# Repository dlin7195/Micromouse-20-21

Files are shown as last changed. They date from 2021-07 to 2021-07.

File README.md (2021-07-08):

# Micromouse-20-21
Maze-solving vehicle implemented using an STM32F405RGT6 microcontroller.
The vehicle detects maze walls using readings from infrared emitter and receiver pairs.
Designed breakout board for IR receivers and emitters using EAGLE.
Uses encoder readings fed into a PID controller for distance and rotation control.

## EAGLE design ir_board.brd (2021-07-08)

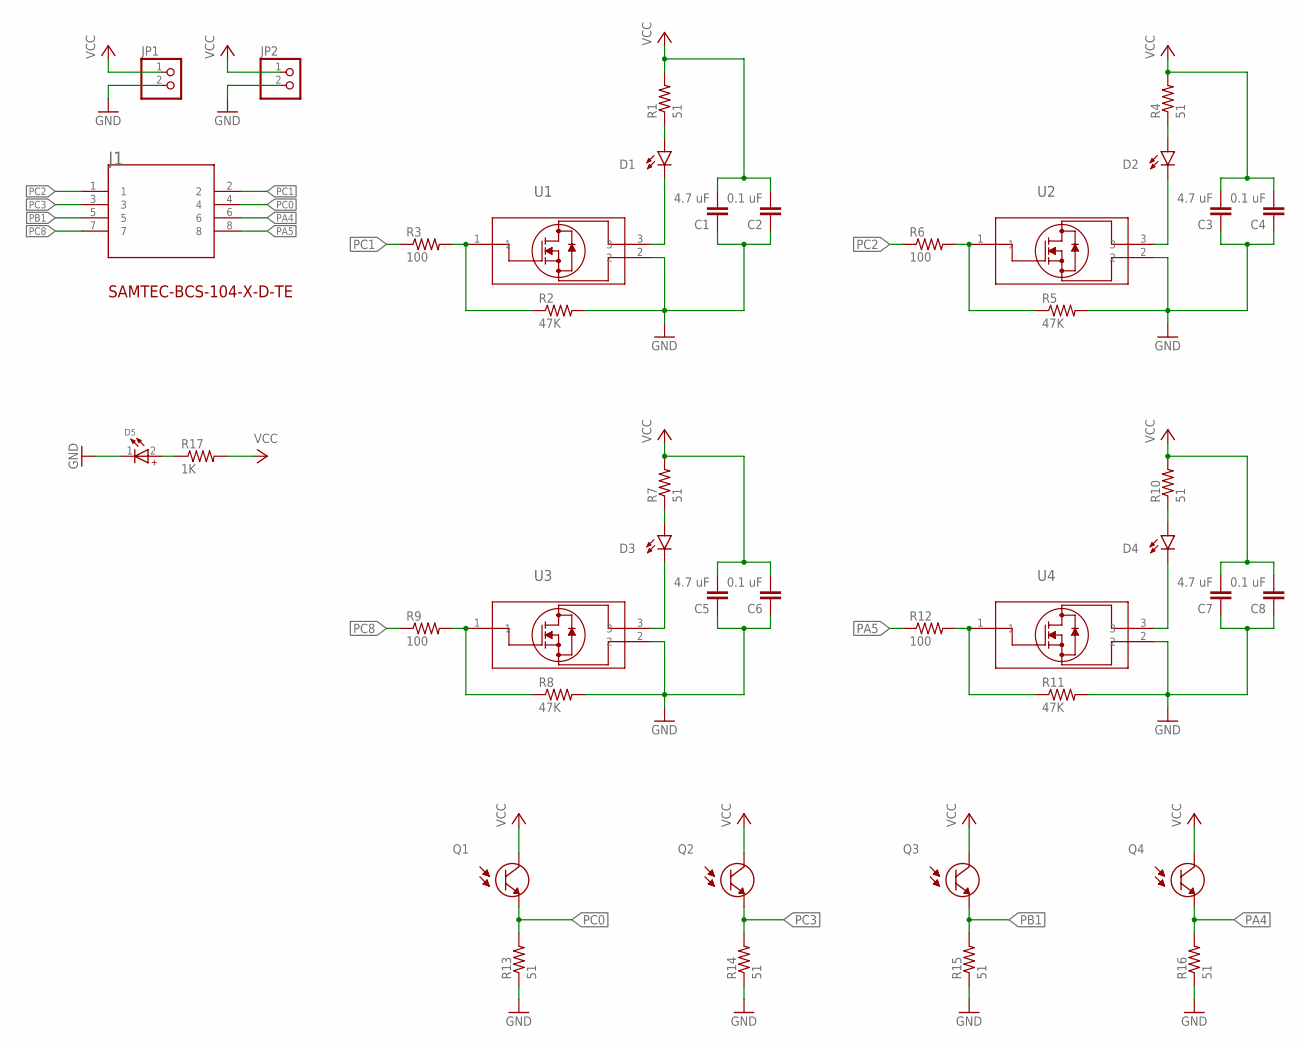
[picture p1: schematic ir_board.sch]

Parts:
C1, C3, C5, C7: 4.7 uF; C0805
C2, C4, C6, C8: 0.1 uF; C0805
D1, D2, D3, D4: LED5MM
D5: WL-SMCW_0805_150080BS75000; WL-SMCW_0805
J1: SAMTEC-BCS-104-X-D-TEJ; SAMTEC-BCS-104-X-D-TE
JP1, JP2: PINHD-1X2; 1X02
Q1, Q2, Q3, Q4: SFH_313_FA-3/4; XDCR_SFH_313_FA-3/4
R1, R4, R7, R10, R13, R14, R15, R16: 51; R0805
R2, R5, R8, R11: 47K; R0805
R3, R6, R9, R12: 100; R0805
R17: 1K; R0805
U1, U2, U3, U4: 2N7002LT1G; SOT-23_3L_ONS

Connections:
GND: C1.1, C2.1, C3.1, C4.1, C5.1, C6.1, C7.1, C8.1, D5.1 (-), JP1.2, JP2.2, R2.2, R5.2, R8.2, R11.2, R13.1, R14.1, R15.1, R16.1, U1.2, U2.2, U3.2, U4.2
unnamed: R2.1, R3.2, U1.1
unnamed: D1.K (C), U1.3
unnamed: D5.2 (+), R17.1
unnamed: D2.A, R4.1
unnamed: D2.K (C), U2.3
unnamed: R8.1, R9.2, U3.1
unnamed: D3.A, R7.1
unnamed: R5.1, R6.2, U2.1
unnamed: R11.1, R12.2, U4.1
unnamed: D4.K (C), U4.3
unnamed: D3.K (C), U3.3
unnamed: D4.A, R10.1
unnamed: D1.A, R1.1
PA4: J1.6, Q4.1 (E), R16.2
PA5: J1.8, R12.1
PB1: J1.5, Q3.1 (E), R15.2
PC0: J1.4, Q1.1 (E), R13.2
PC1: J1.2, R3.1
PC2: J1.1, R6.1
PC3: J1.3, Q2.1 (E), R14.2
PC8: J1.7, R9.1
VCC: C1.2, C2.2, C3.2, C4.2, C5.2, C6.2, C7.2, C8.2, JP1.1, JP2.1, Q1.2 (C), Q2.2 (C), Q3.2 (C), Q4.2 (C), R1.2, R4.2, R7.2, R10.2, R17.2

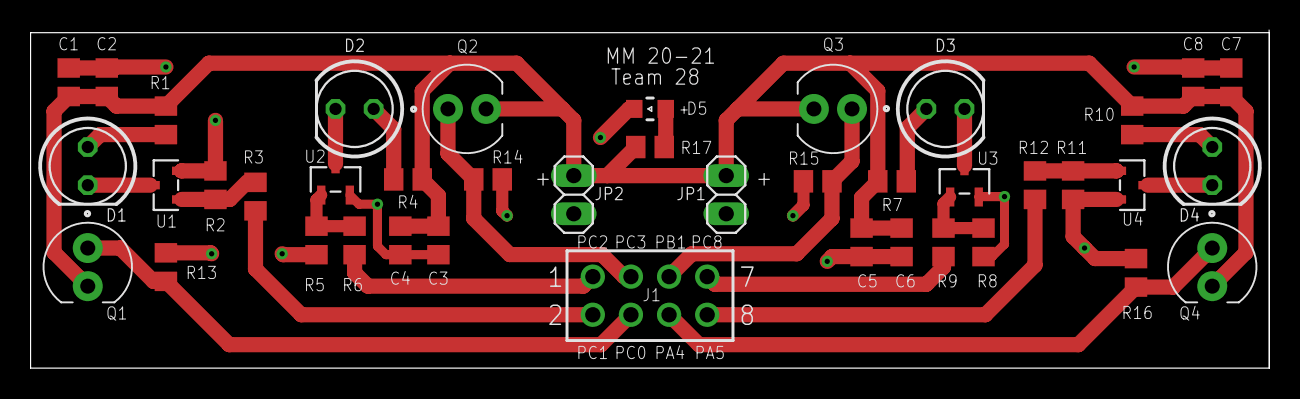
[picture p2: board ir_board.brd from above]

Board: 2 copper layers, 82.5 x 22.4 mm, 41 parts (0 on the bottom side), 23 nets.

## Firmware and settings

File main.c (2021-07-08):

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
/* Includes ------------------------------------------------------------------*/
#include "main.h"

/* USER CODE BEGIN Includes */
#include "encoders.h"
#include "motors.h"
#include "controller.h"
#include "delay.h"
#include "irs.h"
#include "math.h"
/* USER CODE END Includes */

ADC_HandleTypeDef hadc1;
DMA_HandleTypeDef hdma_adc1;

TIM_HandleTypeDef htim2;
TIM_HandleTypeDef htim4;
TIM_HandleTypeDef htim8;

/* USER CODE BEGIN PV */

int16_t left_counts = 0;
int16_t right_counts = 0;

uint16_t curLeft = 0;
uint16_t curFront = 0;
uint16_t curRight = 0;

uint16_t prevFront = 0;
uint16_t prevLeft = 0;
uint16_t prevRight = 0;

uint16_t leftDelta = 200;
uint16_t frontDelta = 50;
uint16_t rightDelta = 200;


/* USER CODE END PV */

void SystemClock_Config(void);
static void MX_GPIO_Init(void);
static void MX_DMA_Init(void);
static void MX_TIM2_Init(void);
static void MX_TIM8_Init(void);
static void MX_TIM4_Init(void);
static void MX_ADC1_Init(void);
/**
  * @brief  The application entry point.
  * @retval int
  */
int main(void)
{
  /* MCU Configuration--------------------------------------------------------*/

  /* Reset of all peripherals, Initializes the Flash interface and the Systick. */

 	HAL_Init();


  /* USER CODE BEGIN Init */

  Delay_Init();

  /* USER CODE END Init */

  /* Configure the system clock */
  SystemClock_Config();

  /* Initialize all configured peripherals */
  MX_GPIO_Init();
  MX_DMA_Init();
  MX_TIM2_Init();
  MX_TIM8_Init();
  MX_TIM4_Init();
  MX_ADC1_Init();
  /* USER CODE BEGIN 2 */

  HAL_TIM_Encoder_Start(&htim2, TIM_CHANNEL_ALL);
  HAL_TIM_Encoder_Start(&htim8, TIM_CHANNEL_ALL);

  HAL_TIM_PWM_Start(&htim4, TIM_CHANNEL_1);
  HAL_TIM_PWM_Start(&htim4, TIM_CHANNEL_2);
  HAL_TIM_PWM_Start(&htim4, TIM_CHANNEL_3);
  HAL_TIM_PWM_Start(&htim4, TIM_CHANNEL_4);

    // set each motor to different speed and direction
  float left = 0.0;
  float right = 0.0;
  setMotorRPWM(right);  // spin forwards
  setMotorLPWM(left);  // spin backwards

 /*
  move(1);
  turn(-1);
  move(1);
  turn(1);
  move(2);
  turn(1);
  move(1); */

  /* USER CODE END 2 */

  /* Infinite loop */
  /* USER CODE BEGIN WHILE */
  while (1)
  {
	left_counts = (int16_t) TIM2->CNT;
	right_counts = (int16_t) TIM8->CNT;

	curLeft = readLeftIR();
	curFront = readFrontIR();
	curRight = readRightIR();

	if (prevFront != 0)
	{
		if ((curFront - prevFront) > frontDelta)
		{
			//if (fabs(curLeft - prevLeft) > leftDelta)
			if (curRight < 1000)
			{
				turn(-1);  //turn right
			}
			//else if (fabs(curRight - prevRight) > rightDelta)
			else if (curLeft < 950)
			{
				turn(1);  // turn right
			}
			else
			{
				// walls on 3 sides
				break;
			}
		}
		else
		{
			move(1);
		}
		//prevFront = curFront;
	}
	//else
	//{
		//prevFront = curFront;
		/*if (curFront < 700)
		{
			move(1);
		}
		else
		{
		if (readLeftIR() < 1580)
		{
			turn(1);
		}
			if (readRightIR() < 1400)
			{
				turn(-1);
			}
			else if (readLeftIR() < 750)
			{
				turn(1);
			}
		}*/
	//}
    prevFront = curFront;
    prevLeft = curLeft;
    prevRight = curRight;

	/*if (readFrontIR() > 800)
	{
		if (readLeftIR() > 1500)
		{
			if (readRightIR() < 770)
			{
				turn(-1);
				//move(1);
			}
		}
		else
		{
			if (readRightIR() > 700)
			{
				if (readLeftIR() < 2000)
				{
					turn(1);
					//move(1);
				}
			}
		}
	}
	else
	{
		move(1);
	} */

    /* USER CODE END WHILE */

    /* USER CODE BEGIN 3 */
  }
  /* USER CODE END 3 */
}

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
/* USER CODE BEGIN 4 */

void HAL_GPIO_EXTI_Callback(uint16_t GPIO_Pin)
{
  if(GPIO_Pin == PushButton_Pin)
  {
	   /* Your code goes here */
	  if(HAL_GPIO_ReadPin(PushButton_GPIO_Port, PushButton_Pin) == GPIO_PIN_SET)
	  {
		  HAL_GPIO_WritePin(LED_GPIO_Port, LED_Pin, GPIO_PIN_RESET);
	  }
	  else
	  {
		  HAL_GPIO_WritePin(LED_GPIO_Port, LED_Pin, GPIO_PIN_SET);
	  }
  }
}

ADC_HandleTypeDef* Get_HADC1_Ptr(void)
{
	return &hadc1;
}


/* USER CODE END 4 */
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


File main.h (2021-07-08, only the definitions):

#define LED_Pin GPIO_PIN_2
#define LED_GPIO_Port GPIOA
#define PushButton_Pin GPIO_PIN_3
#define PushButton_GPIO_Port GPIOA
#define PushButton_EXTI_IRQn EXTI3_IRQn
#define RightEmitter_Pin GPIO_PIN_4
#define RightEmitter_GPIO_Port GPIOA
#define RightReceiver_Pin GPIO_PIN_5
#define RightReceiver_GPIO_Port GPIOA
#define FrontEmitter_Pin GPIO_PIN_6
#define FrontEmitter_GPIO_Port GPIOA
#define FrontReceiver_Pin GPIO_PIN_7
#define FrontReceiver_GPIO_Port GPIOA
#define LeftEmitter_Pin GPIO_PIN_4
#define LeftEmitter_GPIO_Port GPIOC
#define LeftReceiver_Pin GPIO_PIN_5
#define LeftReceiver_GPIO_Port GPIOC

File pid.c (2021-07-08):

/*
 * pid.c
 *
 *  Template created on: Sep 27, 2020
 *      Author: Tyler Price
 */

#include "main.h"
#include "motors.h"
#include "encoders.h"
#include "math.h"

// define variables
int angleError = 0;
int oldAngleError = 0;
float distanceError = 0;
float oldDistanceError = 0;
float angleCorrection = 0;
float distanceCorrection = 0;
float kPw = 0.004;
float kDw = 0.02;
float kPx = 0.0042;
float kDx = 0.02;

int targetAngle = 0;
int targetDistance = 0;
int isAngleDone = 0;
int isDistanceDone = 0;
int isDone = 0;
int i = 0;

int encoderCount_avg = 0;

void resetPID()
{
	/*
	 * Rreset all the PID-assisting variables defined in this file to default values.
	 * Reset your motors and encoder counts.
	 *
	 * Reset distance and error goal values (+ oldDistanceError and oldAngleError) to zero.
	 */
	angleError = 0;
	distanceError = 0;
	angleCorrection = 0;
	distanceCorrection = 0;

	resetMotors();
	resetEncoders();

	oldDistanceError = 0;
	oldAngleError = 0;

	targetAngle = 0;
	targetDistance = 0;
	isAngleDone = 0;
	isDistanceDone = 0;
	isDone = 0;
	i = 0;

	encoderCount_avg = 0;
	return;
}

void updatePID()
{
	/*
	 * PID logic. It should do the following: 
	 * read the encoder counts to determine an error
	 * use that error along with some PD constants in order to determine how to set the motor speeds
	 * then actually set the motor speeds.
	 */

     angleError = targetAngle + (((int16_t) TIM2->CNT) - ((int16_t) TIM8->CNT));
     angleCorrection = kPw * angleError + kDw * (angleError - oldAngleError);
     // limit angleCorrection
     if (angleCorrection > 0.4)
     {
     	angleCorrection = 0.4;
     }
     else if (angleCorrection < -0.4)
     {
     	angleCorrection = -0.4;
     }
     oldAngleError = angleError;


     encoderCount_avg = (((int16_t) TIM2->CNT) + ((int16_t) TIM8->CNT)) / 2;
     distanceError = targetDistance - encoderCount_avg;
     distanceCorrection = kPx * distanceError + kDx * (distanceError - oldDistanceError);
     // limit distanceCorrection
     if (distanceCorrection > 0.4)
     {
    	 distanceCorrection = 0.4;
     }
     else if (distanceCorrection < -0.4)
     {
    	 distanceCorrection = -0.4;
     }
     oldDistanceError = distanceError;

     // set motor speed
     setMotorLPWM(distanceCorrection - angleCorrection);
     setMotorRPWM(distanceCorrection + angleCorrection);
     i++;

     if (i > 50)
     {
    	 if (fabs(angleError) <= 28)
    	 {
    		 isAngleDone = 1;
    		 //isDone = 1;
    	 }
    	 if (fabs(distanceError) <= 28)
    	 {
    	 	 isDistanceDone = 1;
    		 //isDone = 1;
    	 }
    	 i = 0; // reset the index
     }
}

void setPIDGoalD(int16_t distance)
{
	/*
	 * set variable that stores the goal distance.
	 */
	targetDistance = distance;
}

void setPIDGoalA(int16_t angle)
{
	/*
	 * set variable that stores the goal angle.
	 */
	targetAngle = angle;
}

int8_t PIDdone(void)
{
	/*
	 * return true if the rat has achieved the set goal. 
	 * return true only if the error has been sufficiently close to zero for a certain number of SysTick calls in a row.
	 * (will realistically never be actually 0)
	 */
    if (isAngleDone == 1 && isDistanceDone == 1)
    {
	   return 1;
    }
    else
    {
       return 0;
    }
}

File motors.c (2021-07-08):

/*
 * motors.c
 *
 *  Template created on: Sep 10, 2020
 *      Author: Tyler Price
 */

#include "motors.h"
#include "math.h"

/*
 * return PWM_MAX if pwm > PWM_MAX, -PWM_MAX if pwm < -PWM_MAX, and pwm otherwise.
 */
float limitPWM(float pwm)
{
	if (pwm > PWM_MAX)
	{
		return PWM_MAX;
	}
	else if (pwm < -PWM_MAX)
	{
		return -PWM_MAX;
	}
	else
	{
		return pwm;
	}
}

/*
 * controls the left motor speed and direction by setting the timer pulse value for the appropriate channel.
 * All H-bridge inputs use timer 4. TIM4->CCRX = (uint32_t) (limitPWM(pwm) * MAX_TIMER_COUNTS) sets the pulse value for channel x.
 * For the left motor, setting channel 2 makes the wheel spin forward and setting channel 1 makes the wheel spin backwards.
 *
 * The parameter pwm is a value between 0 and 1, representing the percentage of maximum speed to turn the motor. e.g. 0.5 is half speed.
 *
 * IMPORTANT: NEVER SET BOTH THE FORWARD AND BACKWARD CHANNELS TO NON-ZERO VALUES AT THE SAME TIME. As mentioned in lecture, this can
 * destroy your h-bridge. When setting a channel, always set the other channel to zero first.
 *
 * Implemented such that the left wheel spin forwards when pwm is >= 0, and spin backwards when pwm < 0.
 */
void setMotorLPWM(float pwm)
{
	if (pwm >= 0) // spin forwards -> set channel 2 to pulse value, channel 1 to 0
	{
		TIM4->CCR1 = (uint32_t) 0;
		TIM4->CCR2 = (uint32_t) (limitPWM(pwm) * MAX_TIMER_COUNTS);
	}
	else if (pwm < 0)  // spin backwards -> set channel 1 to pulse value, channel 2 to 0
	{
		float absL = fabs(pwm);
		TIM4->CCR2 = (uint32_t) 0;
		TIM4->CCR1 = (uint32_t) (limitPWM(absL) * MAX_TIMER_COUNTS);
	}
}

/*
 * controls the right motor speed and direction by setting the timer pulse value for the appropriate channel.
 * All H-bridge inputs use timer 4. TIM4->CCRX = (uint32_t) (limitPWM(pwm) * MAX_TIMER_COUNTS) sets the pulse value for channel x.
 * For the right motor, setting channel 4 makes the wheel spin forward and setting channel 3 makes the wheel spin backwards.
 *
 * The parameter pwm is a value between 0 and 1, representing the percentage of maximum speed to turn the motor. e.g. 0.5 is half speed.
 *
 * IMPORTANT: NEVER SET BOTH THE FORWARD AND BACKWARD CHANNELS TO NON-ZERO VALUES AT THE SAME TIME. As mentioned in lecture, this can
 * destroy your h-bridge. When setting a channel, always set the other channel to zero first.
 *
 * Implemented such that the right wheel spin forwards when pwm is >= 0, and spin backwards when pwm < 0.
 */
void setMotorRPWM(float pwm)
{
	if (pwm >= 0)  // spin forwards -> set channel 4 to pulse value, channel 3 to 0
	{
		TIM4->CCR3 = (uint32_t) 0;
		TIM4->CCR4 = (uint32_t) (limitPWM(pwm) * MAX_TIMER_COUNTS);
	}
	else if (pwm < 0)  // spin backwards -> set channel 3 to pulse value, channel 4 to 0
	{
        float absR = fabs(pwm);
		TIM4->CCR4 = (uint32_t) 0;
		TIM4->CCR3 = (uint32_t) (limitPWM(absR) * MAX_TIMER_COUNTS);
	}
}

/*
 * Using the two previous setMotorPWM functions, implement resetMotors to set the PWM for both wheels to zero, effectively stopping them.
 */
void resetMotors()
{
	setMotorLPWM(0);
	setMotorRPWM(0);
}

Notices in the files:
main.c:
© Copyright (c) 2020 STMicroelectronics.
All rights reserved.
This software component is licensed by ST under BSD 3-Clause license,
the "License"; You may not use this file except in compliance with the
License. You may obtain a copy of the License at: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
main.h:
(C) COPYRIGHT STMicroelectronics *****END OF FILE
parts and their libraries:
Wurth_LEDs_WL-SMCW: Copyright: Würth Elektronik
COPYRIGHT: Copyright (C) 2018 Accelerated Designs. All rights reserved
